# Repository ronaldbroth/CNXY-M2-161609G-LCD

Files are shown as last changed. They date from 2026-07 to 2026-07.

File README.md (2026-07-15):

# LCD 1602 Panel Cutout Template

A precision mechanical template for mounting a standard
16x2 LCD module in a CNC-machined enclosure.

This project provides reference dimensions for machining a front panel
opening and mounting holes for common 1602 LCD modules used with
Arduino, ESP8266, ESP32, and industrial embedded systems.

------------------------------------------------------------------------

## Purpose

The objective of this project is to eliminate trial-and-error when
machining enclosure front panels for 1602 LCD displays.

The template is intended for:

-   CNC routers
-   CNC milling machines
-   Laser cutting
-   Waterjet cutting
-   Manual machining

------------------------------------------------------------------------

## Features

-   LCD window dimensions
-   Mounting hole locations
-   Fusion 360 source files
-   Ready-to-machine NC Code

------------------------------------------------------------------------

## Supported LCD Modules

This project supports standard HD44780-compatible LCD modules including:

-   DFRobot 1602

------------------------------------------------------------------------

## Repository Contents

``` text
/Fusion
    opening for DF Robert 1602 LCD.f3z

/GCode
    O1001.nc

/Drawings
    Display Cutout and Mounting Holes – Setup Sheet.pdf
    RTA-900.pdf
    RTA-900.step

/Images
    Display Cutout and Mounting Holes – CNC Setup and Machining.mp4

/LICENSE

README.md

------------------------------------------------------------------------

## Recommended Manufacturing Process

1.  Open the Fusion 360 model.
2.  Verify all dimensions against your LCD module.
3.  Generate toolpaths.
4.  Post-process using the GRBL post processor.
5.  Machine the panel.
6.  Verify fit before production.

------------------------------------------------------------------------

## Machine Used

-   Fusion 360
-   SainSmart Genmitsu 3030-PROVer Ultra CNC Router
-   GRBL Controller

------------------------------------------------------------------------

## Revision History

  Revision   Description
  ---------- -----------------
  1.0        Initial release

------------------------------------------------------------------------

## Notes

Although most HD44780-compatible LCD modules are mechanically similar,
manufacturers occasionally change bezel dimensions and mounting hole
spacing.

Always verify dimensions using calipers before machining production
parts.

Contributions and corrections are welcome.

------------------------------------------------------------------------

## License

GNU General Public License v2.0 (GPL-2.0)

------------------------------------------------------------------------

## Author

**Ronald Roth, Ph.D.**\
President\
Roth Technologies, LLC

------------------------------------------------------------------------

## Future Additions

-   Fusion 360 CAD models
-   STEP models
-   DXF files
-   CNC G-code
-   Mounting hardware recommendations
-   3D printable bezel
-   Complete enclosure examples
-   Multiple LCD manufacturer templates
-   OLED display templates
-   TFT display templates

If this repository has been useful, please consider giving it a star rating.

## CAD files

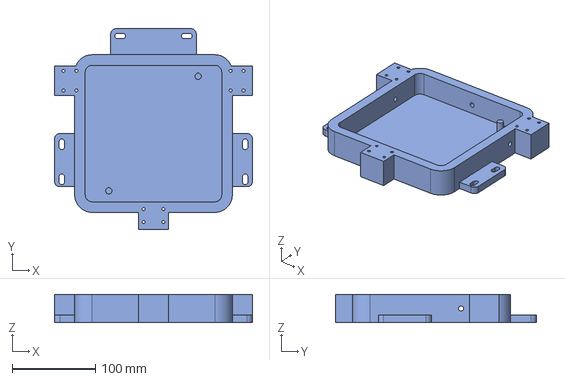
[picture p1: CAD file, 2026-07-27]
RTA-900R2.step
237.6 x 240.8 x 33.9 mm

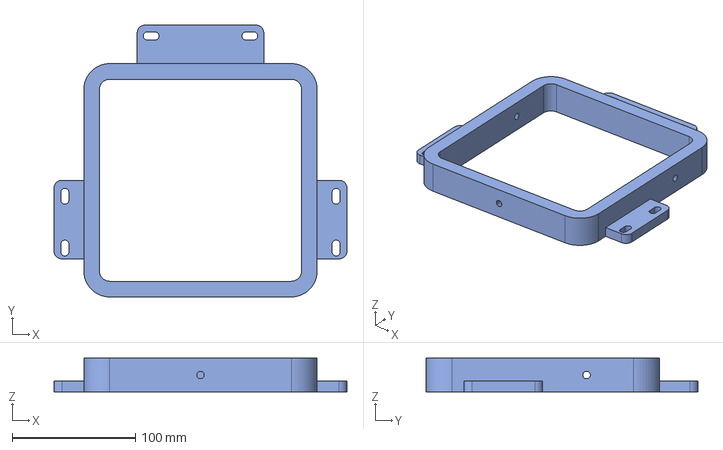
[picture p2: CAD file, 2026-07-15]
RTA-900.step
237.6 x 220.5 x 27.5 mm

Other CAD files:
RTA-900R2.stl
opening for DF Robert 1602 LCD O1001.f3z
opening for DF Robert 1602 LCD O1002.f3z

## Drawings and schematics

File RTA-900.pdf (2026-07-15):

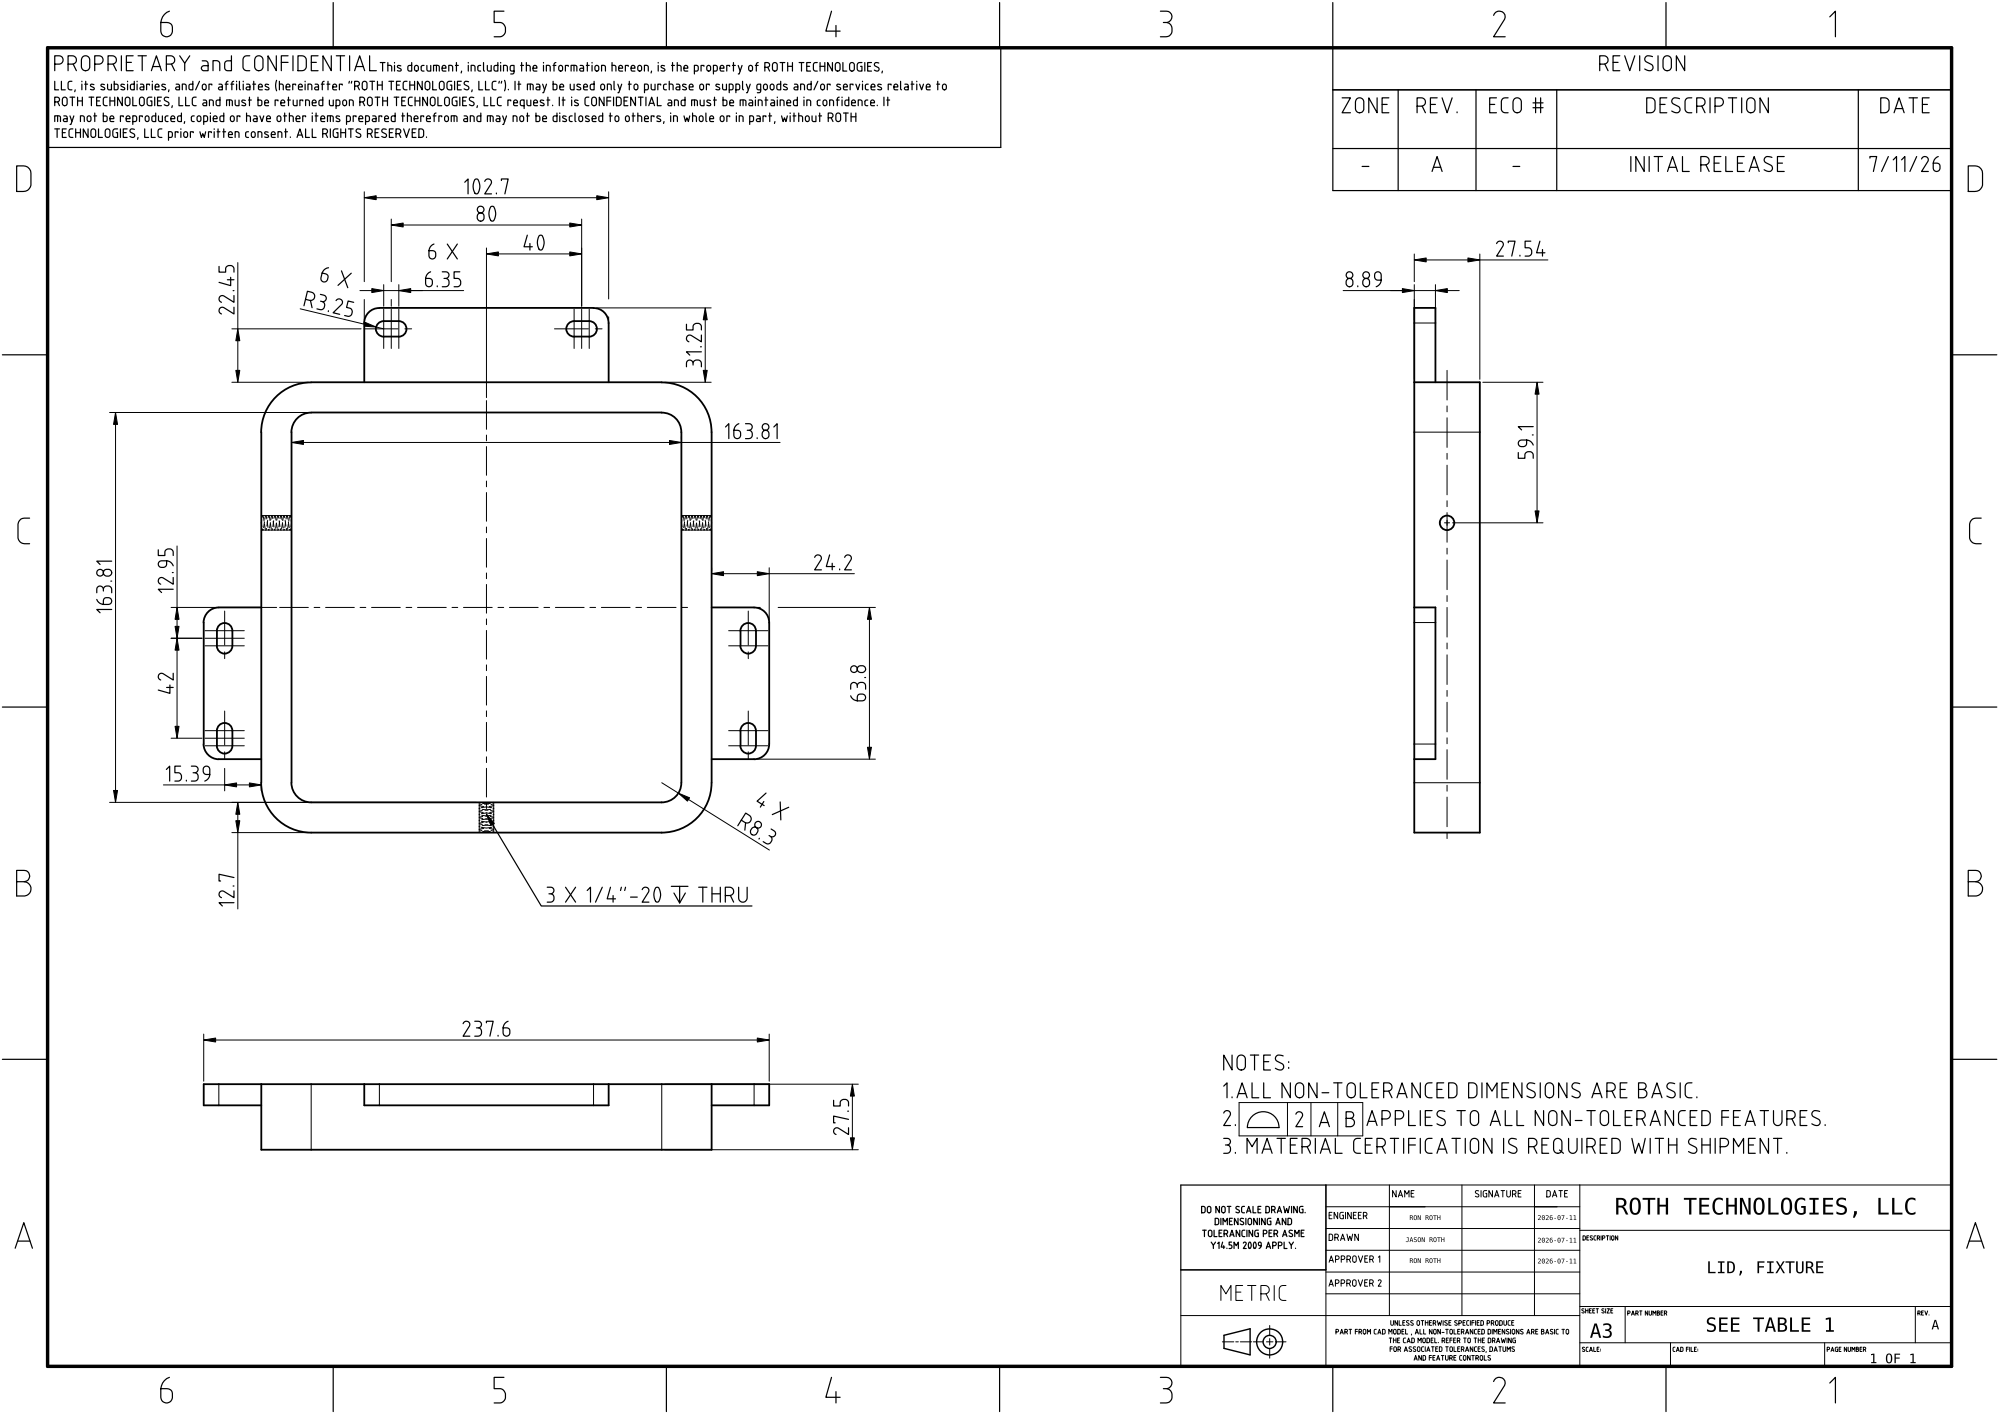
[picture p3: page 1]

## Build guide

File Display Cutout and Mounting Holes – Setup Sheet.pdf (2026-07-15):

## Display Cutout and Mounting Holes – Setup Sheet

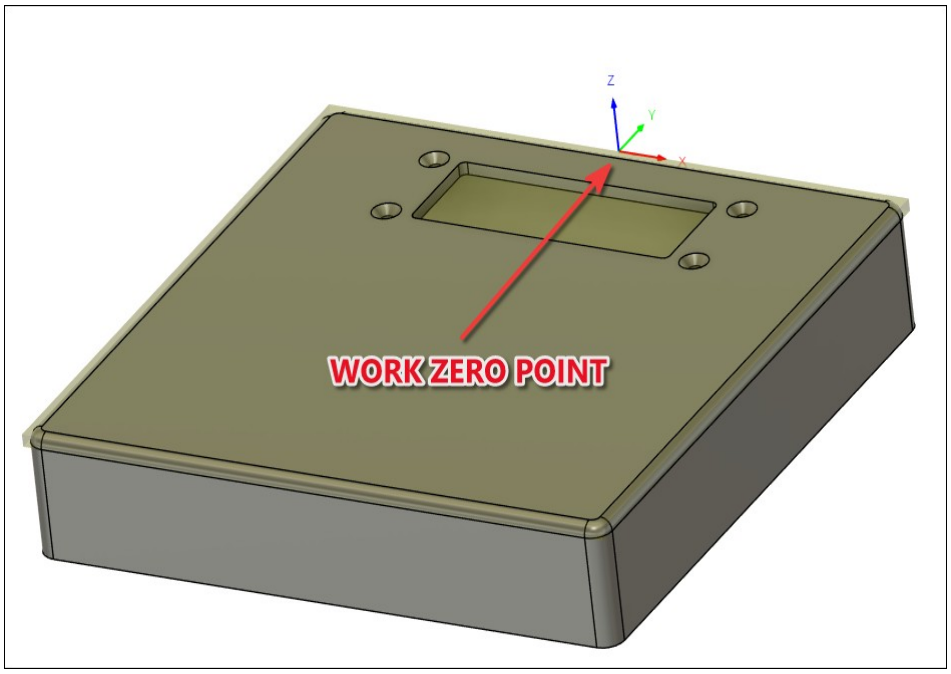
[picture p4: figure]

WORK ZERO POINT
Z0 – top of part
X0 – center of part
Y0 – far edge of part

TOOL - 1/6 ballmill https://tinyurl.com/00625BALL

### 3 Operations: Contouring opening, C-sink, hole

Machining time ~ 2:30 min

File: O1001.NC

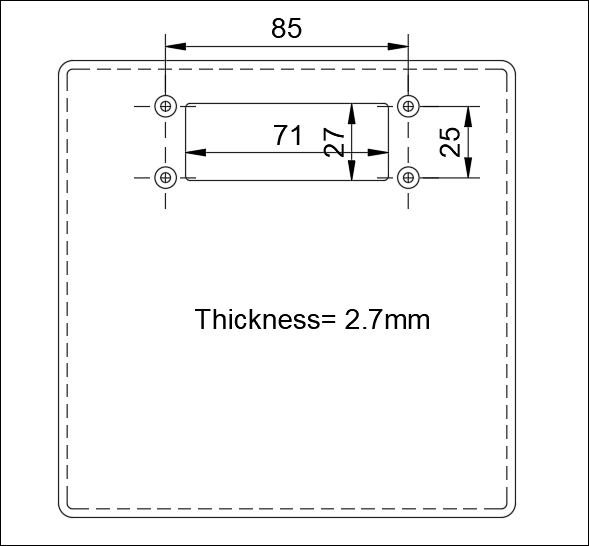
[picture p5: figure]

Part drawing

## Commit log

2026-07-15 Initial publicication
    [opening for DF Robert 1602 LCD.f3z]
2026-07-15 added fixture designed to hold enclosure lid on machining center
    [RTA-900.step]
2026-07-22 updated to O1002
    corrected hole locations to 80x25 from 85x25. the machine tool now starts at the zero point and moves up approximately 5-10 mm vertically before starting the machine cycle. This prevents damage to the lid.
    [opening for DF Robert 1602 LCD O1001.f3z, opening for DF Robert 1602 LCD O1002.f3z]
2026-07-27 new alignment tool for machine center. updated NC file
    [RTA-900R2.step, RTA-900R2.stl]
